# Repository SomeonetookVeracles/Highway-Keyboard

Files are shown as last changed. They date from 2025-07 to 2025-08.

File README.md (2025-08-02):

I'm building a minimalistic keyboard, something simple and stripped down. It's my first time working on a large PCB, and I kept getting distracted by feature creep and add-ons. So I'm going back to basics. I want this to be a barebones board that helps me sharpen my skills and really dial in the core of what makes a great keyboard.

I learned a lot while doing this, and explored concepts like impedence matching and zones, something that I've done before but never really had to prioritize.

If I do this again, I'm using a ESP-32 chip, making a CPU clock with decoupling capacitors was exhausting and annoyed me to no small extent lmao.
473670760-d07d10b8-821d-4425-aa78-196647b4c1dc





# Bill of Materials

| Reference | Qty | Value | Footprint | Description | DigiKey Link | Amazon Link | Unit Price | Total Price |
|---|-----|---|---|---|---|---|---|---|
| **Capacitors** | | | | | | | | |
| C1 | 1 | 1uF | 0603 | Ceramic Capacitor | [YAGEO CC0603ZRY5V7BB105](https://www.digikey.com/en/products/detail/yageo/CC0603ZRY5V7BB105/2103110) | [0603 Capacitor Kit](https://www.amazon.com/100pcs-Multilayer-Ceramic-Capacitor-0-5pF/dp/B0DDC637G1) | $0.03 | $0.03 |
| C2,C3,C4 | 3 | 0.1uF | 0603 | Ceramic Capacitor | [KEMET C0603C104J4RAC7867](https://www.digikey.com/en/products/detail/kemet/C0603C104J4RAC7867/411096) | [0603 Capacitor Kit](https://www.amazon.com/100pcs-Multilayer-Ceramic-Capacitor-0-5pF/dp/B0DDC637G1) | $0.02 | $0.06 |
| C5 | 1 | 10uF | 0603 | Ceramic Capacitor | [YAGEO CC0603KRX5R6BB106](https://www.digikey.com/en/products/detail/yageo/CC0603KRX5R6BB106/5195191) | [0603 Capacitor Kit](https://www.amazon.com/100pcs-Multilayer-Ceramic-Capacitor-0-5pF/dp/B0DDC637G1) | $0.08 | $0.08 |
| C6,C7 | 2 | 22pF | 0603 | Ceramic Capacitor | [DigiKey 0603 Capacitors](https://www.digikey.com/en/products/filter/ceramic-capacitors/60) | [0603 Capacitor Kit](https://www.amazon.com/100pcs-Multilayer-Ceramic-Capacitor-0-5pF/dp/B0DDC637G1) | $0.02 | $0.04 |
| **Diodes** | | | | | | | | |
| D1-D87 | 87 | D_Small | 0603 | Small Signal Diode | [DigiKey 0603 Diodes](https://www.digikey.com/en/products/filter/diodes-rectifiers-single/280) | [SMD Component Kit](https://www.amazon.com/Component-Assortment-Capacitor-Transistor-Soldering/dp/B07GMRJC1Q) | $0.05 | $4.35 |
| **Fuse** | | | | | | | | |
| F1 | 1 | 500mA | 1812 | PTC Resettable Fuse | [Bourns MF-MSMF050-2](https://www.digikey.com/en/products/detail/bourns-inc/MF-MSMF050-2/662832) | [Fuse Kit](https://www.amazon.com/s?k=500mA+PTC+fuse) | $0.32 | $0.32 |
| **Connectors** | | | | | | | | |
| J1 | 1 | USB_C_Receptacle | HRO TYPE-C-31-M-12 | USB-C 2.0 Connector | [JAE DX07S016JA3R1500](https://www.digikey.com/en/products/detail/jae-electronics/DX07S016JA3R1500/5978550) | [USB-C Connector](https://www.amazon.com/s?k=TYPE-C-31-M-12) | $0.38 | $0.38 |
| **Resistors** | | | | | | | | |
| R1,R4 | 2 | 10k | 0603 | Chip Resistor | [YAGEO RC0603JR-0710KL](https://www.digikey.com/en/products/detail/yageo/RC0603JR-0710KL/726700) | [0603 Resistor Kit](https://www.amazon.com/s?k=0603+resistor+kit) | $0.01 | $0.02 |
| R2,R3 | 2 | 22Ω | 0603 | Chip Resistor | [DigiKey 0603 Resistors](https://www.digikey.com/en/products/filter/resistors/chip-resistor-surface-mount/0603/52) | [0603 Resistor Kit](https://www.amazon.com/s?k=0603+resistor+kit) | $0.01 | $0.02 |
| R5 | 1 | 1M | 0603 | Chip Resistor | [DigiKey 0603 Resistors](https://www.digikey.com/en/products/filter/resistors/chip-resistor-surface-mount/0603/52) | [0603 Resistor Kit](https://www.amazon.com/s?k=0603+resistor+kit) | $0.01 | $0.01 |
| R6,R7 | 2 | 5.11k | 0603 | Chip Resistor | [DigiKey 0603 Resistors](https://www.digikey.com/en/products/filter/resistors/chip-resistor-surface-mount/0603/52) | [0603 Resistor Kit](https://www.amazon.com/s?k=0603+resistor+kit) | $0.01 | $0.02 |
| **Switches** | | | | | | | | |
| SW1-SW87 | 87 | SW_Push_45deg | Cherry MX Compatible | Mechanical Key Switch | [Cherry MX1A-E1NW](https://www.digikey.com/en/products/detail/cherry-americas-llc/MX1A-E1NW/20180) | [Cherry MX Switches](https://www.amazon.com/s?k=cherry+mx+switches) | $1.25 | $108.75 |
| SWRST1 | 1 | SW_PUSH | SMD Tactile | Reset Switch | [DigiKey Tactile Switches](https://www.digikey.com/en/products/filter/tactile-switches/197) | [Tactile Switch Kit](https://www.amazon.com/s?k=SMD+tactile+switch) | $0.15 | $0.15 |
| **Microcontroller** | | | | | | | | |
| U1 | 1 | ATmega32U4-A | TQFP-44 | 8-bit Microcontroller | [ATMEGA32U4-AU](https://www.digikey.com/en/products/detail/microchip-technology/ATMEGA32U4-AU/1914602) | [ATmega32U4 Module](https://www.amazon.com/s?k=atmega32u4) | $5.39 | $5.39 |
| **Crystal** | | | | | | | | |
| Y1 | 1 | 16MHz | 0603-4Pin | Crystal Oscillator | [TXC 7V-16.000MAAE-T](https://www.digikey.com/en/products/detail/txc-corporation/7V-16-000MAAE-T/2626978) | [16MHz Crystal](https://www.amazon.com/s?k=16MHz+crystal+SMD) | $0.35 | $0.35 |

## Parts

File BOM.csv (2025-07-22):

Reference | Qty | Value | DNP | Exclude from BOM | Exclude from Board | Footprint | Datasheet
C1 | 1 | 1uF |  |  |  | Capacitor_SMD:C_0201_0603Metric_Pad0.64x0.40mm_HandSolder | ~
C2,C3,C4 | 3 | 0.1uF |  |  |  | Capacitor_SMD:C_0201_0603Metric_Pad0.64x0.40mm_HandSolder | ~
C5 | 1 | 10uF |  |  |  | Capacitor_SMD:C_0201_0603Metric_Pad0.64x0.40mm_HandSolder | ~
C6,C7 | 2 | 22pF |  |  |  | Capacitor_SMD:C_0201_0603Metric_Pad0.64x0.40mm_HandSolder | ~
D1,D2,D3,D4,D5,D6,D7,D8,D9,D10,D11,D12,D13,D14,D15,D16,D17,D18,D19,D20,D21,D22,D23,D24,D25,D26,D27,D28,D29,D30,D31,D32,D33,D34,D35,D36,D37,D38,D39,D40,D41,D42,D43,D44,D45,D46,D47,D48,D49,D50,D51,D52,D53,D54,D55,D56,D57,D58,D59,D60,D61,D62,D63,D64,D65,D66,D67,D68,D69,D70,D71,D72,D73,D74,D75,D76,D77,D78,D79,D80,D81,D82,D83,D84,D85,D86,D87 | 87 | D_Small |  |  |  | Diode_SMD:D_0603_1608Metric_Pad1.05x0.95mm_HandSolder | ~
F1 | 1 | 500mA |  |  |  | Fuse:Fuse_Bourns_MF-RG500 | ~
J1 | 1 | USB_C_Receptacle_USB2.0_14P |  |  |  | Connector_USB:USB_C_Receptacle_HRO_TYPE-C-31-M-12 | https://www.usb.org/sites/default/files/documents/usb_type-c.zip
R1,R4 | 2 | 10k |  |  |  | Resistor_SMD:R_0201_0603Metric_Pad0.64x0.40mm_HandSolder | ~
R2,R3 | 2 | 22 |  |  |  | Resistor_SMD:R_0201_0603Metric_Pad0.64x0.40mm_HandSolder | ~
R5 | 1 | 1M |  |  |  | Resistor_SMD:R_0201_0603Metric_Pad0.64x0.40mm_HandSolder | ~
R6,R7 | 2 | 5.11k |  |  |  | Resistor_SMD:R_0201_0603Metric_Pad0.64x0.40mm_HandSolder | ~
SW1,SW2,SW3,SW4,SW5,SW6,SW7,SW8,SW9,SW10,SW11,SW12,SW13,SW14,SW15,SW16,SW17,SW18,SW19,SW20,SW21,SW22,SW23,SW24,SW25,SW26,SW27,SW28,SW29,SW30,SW31,SW32,SW33,SW34,SW35,SW36,SW37,SW38,SW39,SW40,SW41,SW42,SW43,SW44,SW45,SW46,SW47,SW48,SW49,SW50,SW51,SW52,SW53,SW54,SW55,SW56,SW57,SW58,SW59,SW60,SW61,SW62,SW63,SW64,SW65,SW66,SW67,SW68,SW69,SW70,SW71,SW72,SW73,SW74,SW75,SW76,SW77,SW78,SW79,SW80,SW81,SW82,SW83,SW84,SW85,SW86,SW87 | 87 | SW_Push_45deg |  |  |  | PCM_Switch_Keyboard_Hybrid:SW_Hybrid_Cherry_MX_Alps | ~
SWRST1 | 1 | SW_PUSH |  |  |  | Button_Switch_SMD:SW_Push_1P1T_NO_CK_KMR2
U1 | 1 | ATmega32U4-A |  |  |  | Package_QFP:TQFP-44_10x10mm_P0.8mm | http://ww1.microchip.com/downloads/en/DeviceDoc/Atmel-7766-8-bit-AVR-ATmega16U4-32U4_Datasheet.pdf
Y1 | 1 | 16MHz |  |  |  | Crystal:Crystal_SMD_0603-4Pin_6.0x3.5mm_HandSoldering | ~

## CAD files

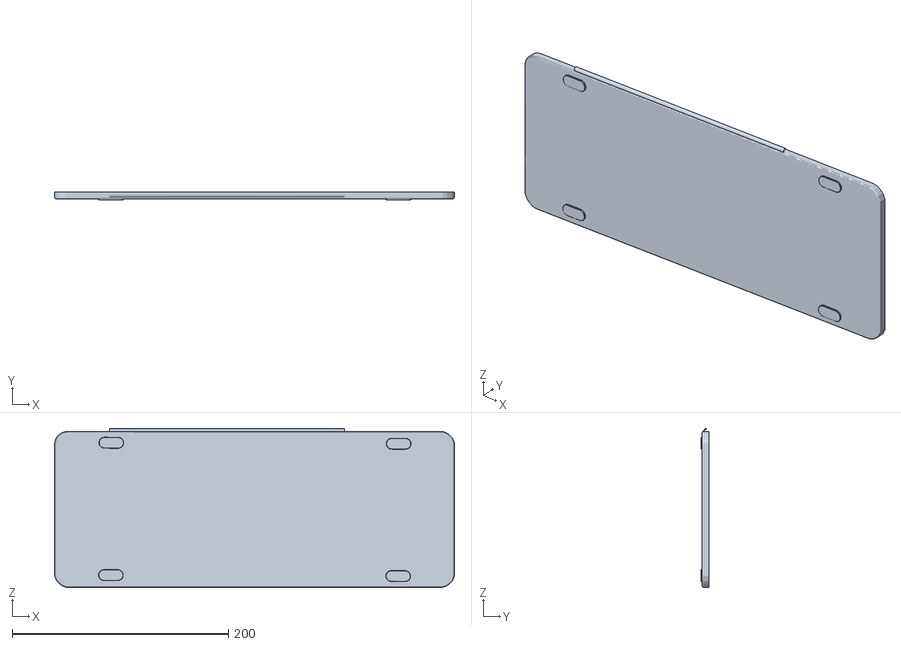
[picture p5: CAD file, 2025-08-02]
100% Keyboard/CAD Files/Bottom.STL
369.6 x 7.65 x 146.9

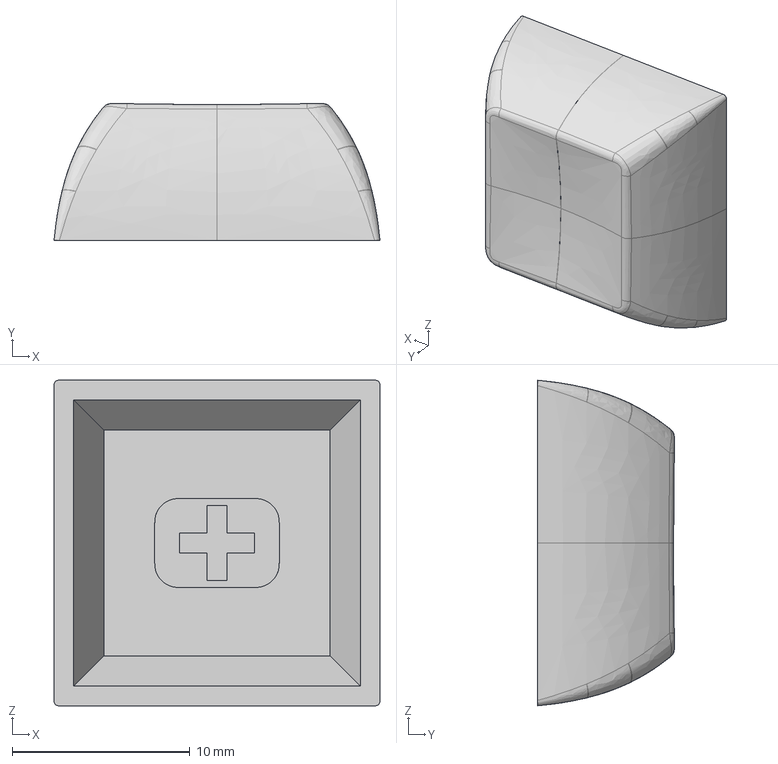
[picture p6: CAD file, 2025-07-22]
100% Keyboard/CAD Files/dsa-keycap-for-cherry-mx-switches-1.snapshot.4/DSA_Keycap_CherryMX.step
18.3 x 7.69 x 18.3 mm

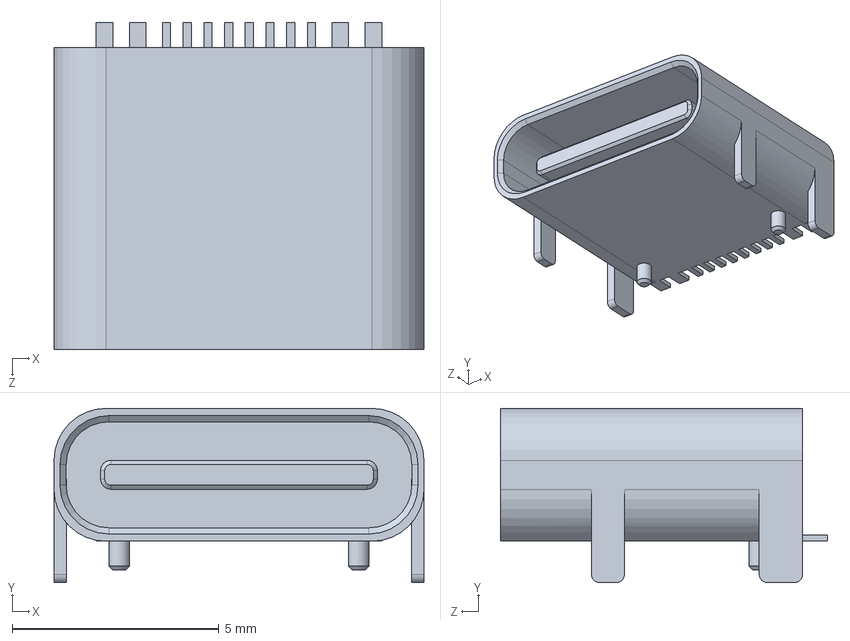
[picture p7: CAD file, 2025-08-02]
100% Keyboard/CAD Files/HRO TYPE-C-31-M-12.SLDPRT
8.94 x 4.21 x 7.90 mm

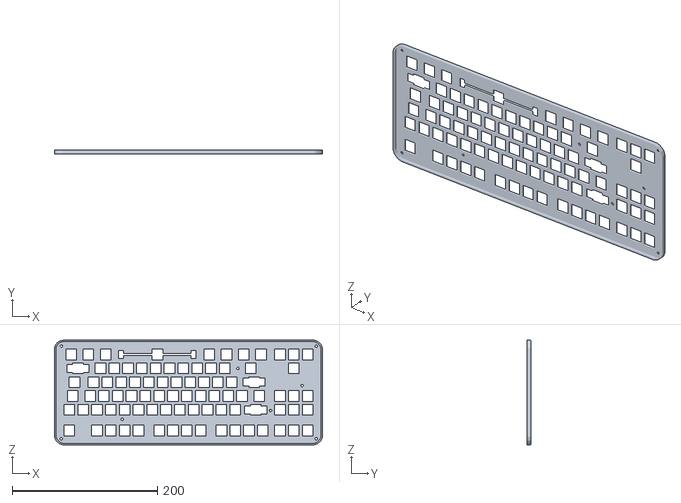
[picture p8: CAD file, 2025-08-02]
100% Keyboard/CAD Files/Top.STL
369.6 x 5.14 x 144.3

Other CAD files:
100% Keyboard/CAD Files/Top 2.STL
100% Keyboard/CAD Files/Bottom 2.STL
100% Keyboard/CAD Files/dsa-keycap-for-cherry-mx-switches-1.snapshot.4/Keycap_adjusted v39.f3d

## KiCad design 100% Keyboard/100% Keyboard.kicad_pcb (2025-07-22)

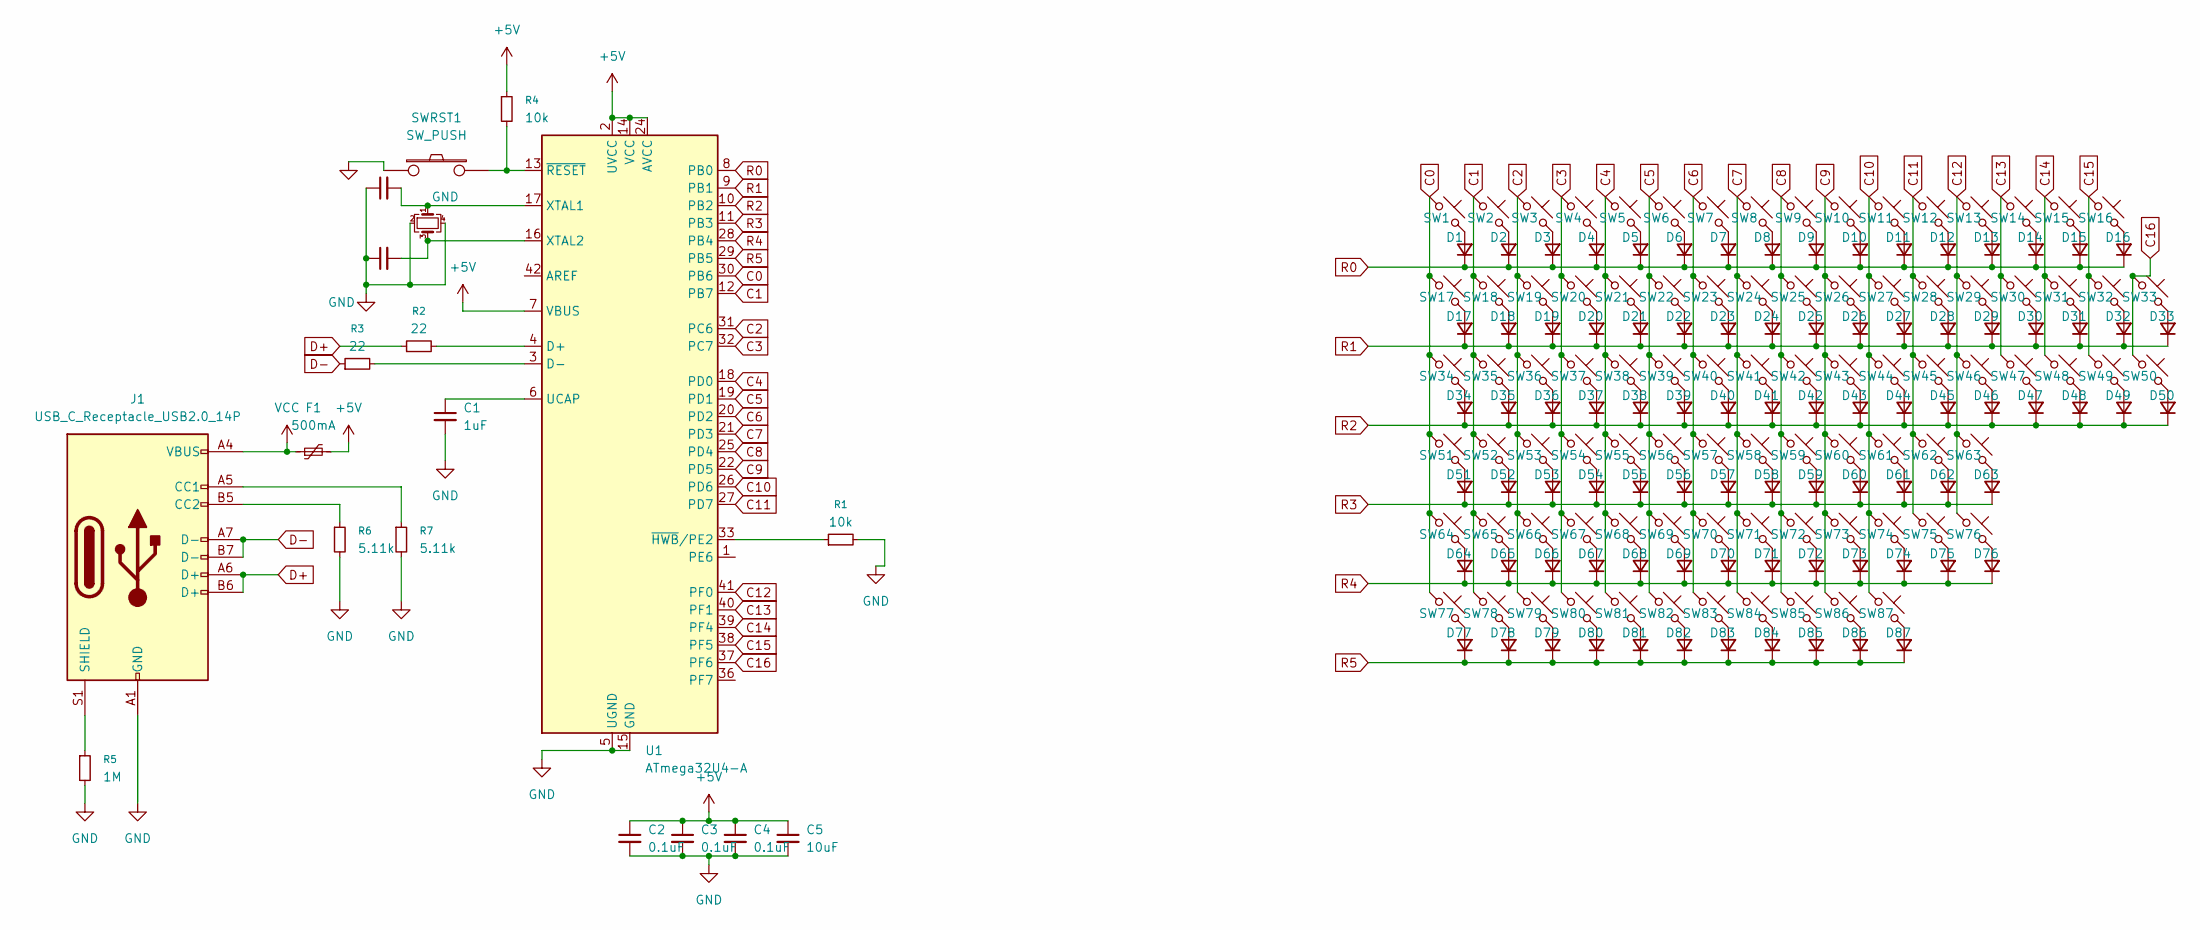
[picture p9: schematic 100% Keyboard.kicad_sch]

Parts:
C1: 1uF; C_0201_0603Metric_Pad0.64x0.40mm_HandSolder
C2, C3, C4: 0.1uF; C_0201_0603Metric_Pad0.64x0.40mm_HandSolder
C5: 10uF; C_0201_0603Metric_Pad0.64x0.40mm_HandSolder
C6, C7: 22pF; C_0201_0603Metric_Pad0.64x0.40mm_HandSolder
D1, D2, D3, D4, D5, D6, D7, D8, D9, D10, D11, D12, D13, D14, D15, D16, D17, D18, D19, D20, D21, D22, D23, D24, D25, D26, D27, D28, D29, D30, D31, D32, D33, D34, D35, D36, D37, D38, D39, D40, D41, D42, D43, D44, D45, D46, D47, D48, D49, D50, D51, D52, D53, D54, D55, D56, D57, D58, D59, D60, D61, D62, D63, D64, D65, D66, D67, D68, D69, D70, D71, D72, D73, D74, D75, D76, D77, D78, D79, D80, D81, D82, D83, D84, D85, D86, D87: D_Small; D_0603_1608Metric_Pad1.05x0.95mm_HandSolder
F1: 500mA; Fuse_Bourns_MF-RG500
J1: USB_C_Receptacle_USB2.0_14P; USB_C_Receptacle_HRO_TYPE-C-31-M-12
R1, R4: 10k; R_0201_0603Metric_Pad0.64x0.40mm_HandSolder
R2, R3: 22; R_0201_0603Metric_Pad0.64x0.40mm_HandSolder
R5: 1M; R_0201_0603Metric_Pad0.64x0.40mm_HandSolder
R6, R7: 5.11k; R_0201_0603Metric_Pad0.64x0.40mm_HandSolder
SW1, SW2, SW3, SW4, SW5, SW6, SW7, SW8, SW9, SW10, SW11, SW12, SW13, SW14, SW15, SW16, SW17, SW18, SW19, SW20, SW21, SW22, SW23, SW24, SW25, SW26, SW27, SW28, SW29, SW30, SW31, SW32, SW33, SW34, SW35, SW36, SW37, SW38, SW39, SW40, SW41, SW42, SW43, SW44, SW45, SW46, SW47, SW48, SW49, SW50, SW51, SW52, SW53, SW54, SW55, SW56, SW57, SW58, SW59, SW60, SW61, SW62, SW63, SW64, SW65, SW66, SW67, SW68, SW69, SW70, SW71, SW72, SW73, SW74, SW75, SW76, SW77, SW78, SW79, SW80, SW81, SW82, SW83, SW84, SW85, SW86, SW87: SW_Push_45deg; SW_Hybrid_Cherry_MX_Alps
SWRST1: SW_PUSH; SW_Push_1P1T_NO_CK_KMR2
U1: ATmega32U4-A; TQFP-44_10x10mm_P0.8mm
Y1: 16MHz; Crystal_SMD_0603-4Pin_6.0x3.5mm_HandSoldering

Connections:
+5V: C2.1, C3.1, C4.1, C5.1, F1.2, R4.1, U1.2 (UVCC), U1.7 (VBUS), U1.14 (VCC), U1.24 (AVCC), U1.34 (VCC), U1.44 (AVCC)
C0: SW1.1, SW17.1, SW34.1, SW51.1, SW64.1, SW77.1, U1.30 (PB6)
C1: SW2.1, SW18.1, SW35.1, SW52.1, SW65.1, SW78.1, U1.12 (PB7)
C2: SW3.1, SW19.1, SW36.1, SW53.1, SW66.1, SW79.1, U1.31 (PC6)
C3: SW4.1, SW20.1, SW37.1, SW54.1, SW67.1, SW80.1, U1.32 (PC7)
C4: SW5.1, SW21.1, SW38.1, SW55.1, SW68.1, SW81.1, U1.18 (PD0)
C5: SW6.1, SW22.1, SW39.1, SW56.1, SW69.1, SW82.1, U1.19 (PD1)
C6: SW7.1, SW23.1, SW40.1, SW57.1, SW70.1, SW83.1, U1.20 (PD2)
C7: SW8.1, SW24.1, SW41.1, SW58.1, SW71.1, SW84.1, U1.21 (PD3)
C8: SW9.1, SW25.1, SW42.1, SW59.1, SW72.1, SW85.1, U1.25 (PD4)
C9: SW10.1, SW26.1, SW43.1, SW60.1, SW73.1, SW86.1, U1.22 (PD5)
C10: SW11.1, SW27.1, SW44.1, SW61.1, SW74.1, SW87.1, U1.26 (PD6)
C11: SW12.1, SW28.1, SW45.1, SW62.1, SW75.1, U1.27 (PD7)
C12: SW13.1, SW29.1, SW46.1, SW63.1, SW76.1, U1.41 (PF0)
C13: SW14.1, SW30.1, SW47.1, U1.40 (PF1)
C14: SW15.1, SW31.1, SW48.1, U1.39 (PF4)
C15: SW16.1, SW32.1, SW49.1, U1.38 (PF5)
C16: SW33.1, SW50.1, U1.37 (PF6)
D+: J1.A6 (D+), J1.B6 (D+), R2.1
D-: J1.A7 (D-), J1.B7 (D-), R3.1
GND: C1.2, C2.2, C3.2, C4.2, C5.2, C6.1, C7.1, J1.A1 (GND), J1.A12 (GND), J1.B1 (GND), J1.B12 (GND), R1.2, R5.2, R6.2, R7.2, SWRST1.1, U1.5 (UGND), U1.15 (GND), U1.23 (GND), U1.35 (GND), U1.43 (GND), Y1.2, Y1.4
unnamed: D1.2 (A), SW1.2
unnamed: D2.2 (A), SW2.2
unnamed: D3.2 (A), SW3.2
unnamed: D4.2 (A), SW4.2
unnamed: D5.2 (A), SW5.2
unnamed: D6.2 (A), SW6.2
unnamed: D7.2 (A), SW7.2
unnamed: D8.2 (A), SW8.2
unnamed: D9.2 (A), SW9.2
unnamed: D10.2 (A), SW10.2
unnamed: D11.2 (A), SW11.2
unnamed: D12.2 (A), SW12.2
unnamed: D13.2 (A), SW13.2
unnamed: D14.2 (A), SW14.2
unnamed: D15.2 (A), SW15.2
unnamed: D16.2 (A), SW16.2
unnamed: D17.2 (A), SW17.2
unnamed: D18.2 (A), SW18.2
unnamed: D19.2 (A), SW19.2
unnamed: D20.2 (A), SW20.2
unnamed: D21.2 (A), SW21.2
unnamed: D22.2 (A), SW22.2
unnamed: D23.2 (A), SW23.2
unnamed: D24.2 (A), SW24.2
unnamed: D25.2 (A), SW25.2
unnamed: D26.2 (A), SW26.2
unnamed: D27.2 (A), SW27.2
unnamed: D28.2 (A), SW28.2
unnamed: D29.2 (A), SW29.2
unnamed: D30.2 (A), SW30.2
unnamed: D31.2 (A), SW31.2
unnamed: D32.2 (A), SW32.2
unnamed: D33.2 (A), SW33.2
unnamed: D34.2 (A), SW34.2
unnamed: D35.2 (A), SW35.2
unnamed: D36.2 (A), SW36.2
unnamed: D37.2 (A), SW37.2
unnamed: D38.2 (A), SW38.2
unnamed: D39.2 (A), SW39.2
unnamed: D40.2 (A), SW40.2
unnamed: D41.2 (A), SW41.2
unnamed: D42.2 (A), SW42.2
unnamed: D43.2 (A), SW43.2
unnamed: D44.2 (A), SW44.2
unnamed: D45.2 (A), SW45.2
unnamed: D46.2 (A), SW46.2
unnamed: D47.2 (A), SW47.2
unnamed: D48.2 (A), SW48.2
unnamed: D49.2 (A), SW49.2
unnamed: D50.2 (A), SW50.2
unnamed: D51.2 (A), SW51.2
unnamed: D52.2 (A), SW52.2
unnamed: D53.2 (A), SW53.2
unnamed: D54.2 (A), SW54.2
unnamed: D55.2 (A), SW55.2
unnamed: D56.2 (A), SW56.2
unnamed: D57.2 (A), SW57.2
unnamed: D58.2 (A), SW58.2
unnamed: D59.2 (A), SW59.2
unnamed: D60.2 (A), SW60.2
unnamed: D61.2 (A), SW61.2
unnamed: D62.2 (A), SW62.2
unnamed: D63.2 (A), SW63.2
unnamed: D64.2 (A), SW64.2
unnamed: D65.2 (A), SW65.2
unnamed: D66.2 (A), SW66.2
unnamed: D67.2 (A), SW67.2
unnamed: D68.2 (A), SW68.2
unnamed: D69.2 (A), SW69.2
unnamed: D70.2 (A), SW70.2
unnamed: D71.2 (A), SW71.2
unnamed: D72.2 (A), SW72.2
unnamed: D73.2 (A), SW73.2
unnamed: D74.2 (A), SW74.2
unnamed: D75.2 (A), SW75.2
unnamed: D76.2 (A), SW76.2
unnamed: D77.2 (A), SW77.2
unnamed: D78.2 (A), SW78.2
unnamed: D79.2 (A), SW79.2
unnamed: D80.2 (A), SW80.2
unnamed: D81.2 (A), SW81.2
unnamed: D82.2 (A), SW82.2
unnamed: D83.2 (A), SW83.2
unnamed: D84.2 (A), SW84.2
unnamed: D85.2 (A), SW85.2
unnamed: D86.2 (A), SW86.2
unnamed: D87.2 (A), SW87.2
unnamed: J1.A5 (CC1), R7.1
unnamed: J1.B5 (CC2), R6.1
unnamed: J1.S1 (SHIELD), R5.1
unnamed: R2.2, U1.4 (D+)
unnamed: R3.2, U1.3 (D-)
unnamed: C1.1, U1.6 (UCAP)
unnamed: C6.2, U1.17 (XTAL1), Y1.1
unnamed: C7.2, U1.16 (XTAL2), Y1.3
unnamed: R1.1, U1.33 (~HWB/PE2)
unnamed: R4.2, SWRST1.2, U1.13 (~RESET)
R0: D1.1 (K), D2.1 (K), D3.1 (K), D4.1 (K), D5.1 (K), D6.1 (K), D7.1 (K), D8.1 (K), D9.1 (K), D10.1 (K), D11.1 (K), D12.1 (K), D13.1 (K), D14.1 (K), D15.1 (K), D16.1 (K), U1.8 (PB0)
R1: D17.1 (K), D18.1 (K), D19.1 (K), D20.1 (K), D21.1 (K), D22.1 (K), D23.1 (K), D24.1 (K), D25.1 (K), D26.1 (K), D27.1 (K), D28.1 (K), D29.1 (K), D30.1 (K), D31.1 (K), D32.1 (K), D33.1 (K), U1.9 (PB1)
R2: D34.1 (K), D35.1 (K), D36.1 (K), D37.1 (K), D38.1 (K), D39.1 (K), D40.1 (K), D41.1 (K), D42.1 (K), D43.1 (K), D44.1 (K), D45.1 (K), D46.1 (K), D47.1 (K), D48.1 (K), D49.1 (K), D50.1 (K), U1.10 (PB2)
R3: D51.1 (K), D52.1 (K), D53.1 (K), D54.1 (K), D55.1 (K), D56.1 (K), D57.1 (K), D58.1 (K), D59.1 (K), D60.1 (K), D61.1 (K), D62.1 (K), D63.1 (K), U1.11 (PB3)
R4: D64.1 (K), D65.1 (K), D66.1 (K), D67.1 (K), D68.1 (K), D69.1 (K), D70.1 (K), D71.1 (K), D72.1 (K), D73.1 (K), D74.1 (K), D75.1 (K), D76.1 (K), U1.28 (PB4)
R5: D77.1 (K), D78.1 (K), D79.1 (K), D80.1 (K), D81.1 (K), D82.1 (K), D83.1 (K), D84.1 (K), D85.1 (K), D86.1 (K), D87.1 (K), U1.29 (PB5)
VCC: F1.1, J1.A4 (VBUS), J1.A9 (VBUS), J1.B4 (VBUS), J1.B9 (VBUS)

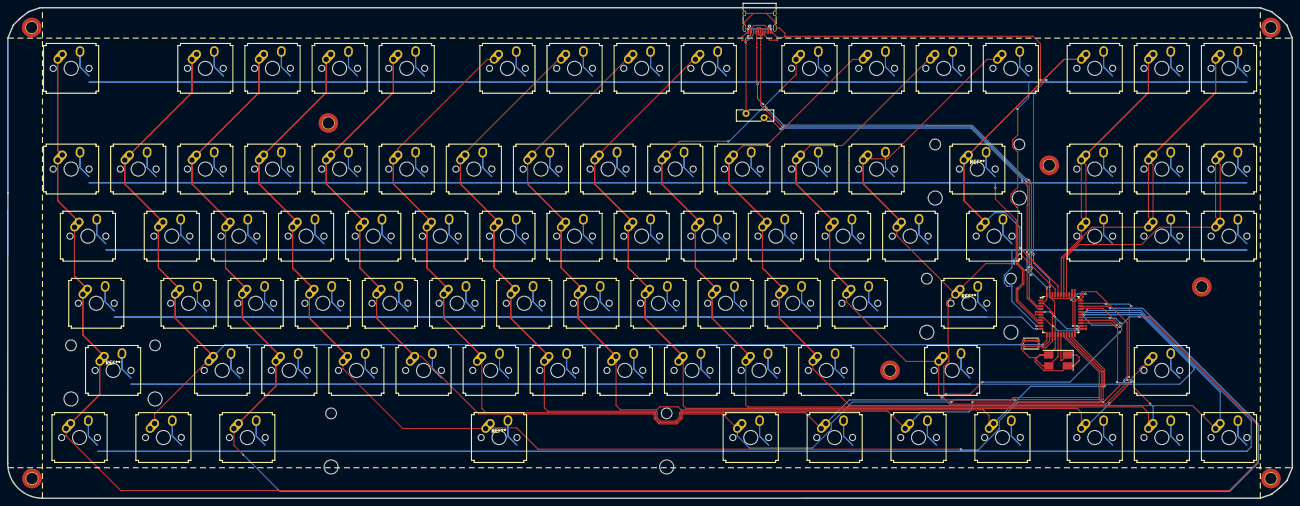
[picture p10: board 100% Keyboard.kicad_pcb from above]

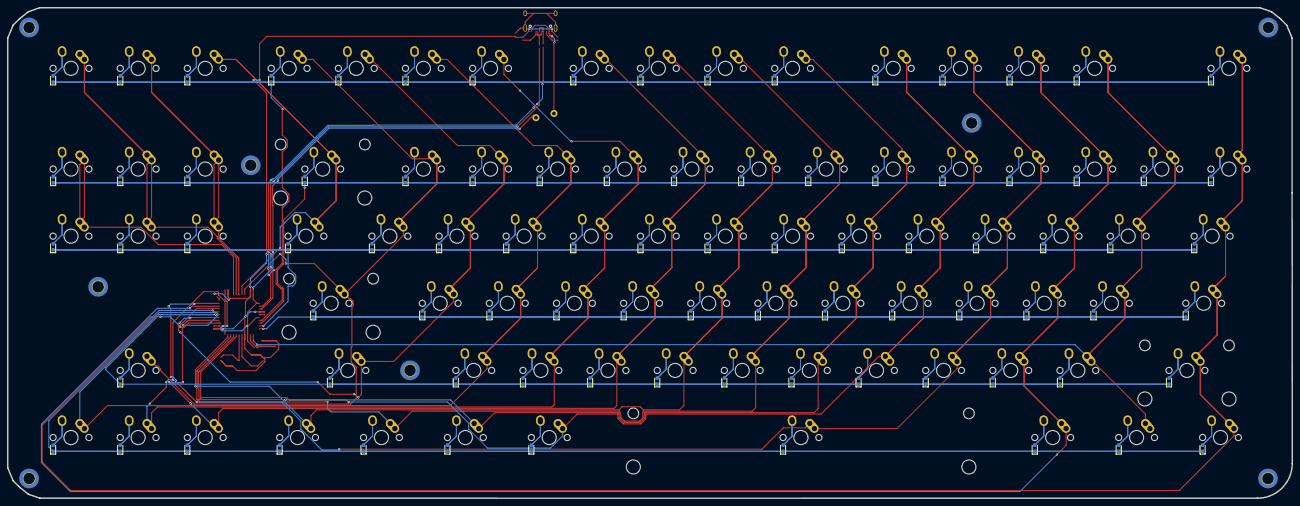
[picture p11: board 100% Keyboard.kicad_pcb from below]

Board: 2 copper layers, 364.6 x 139.2 mm, 193 parts (87 on the bottom side), 125 nets.

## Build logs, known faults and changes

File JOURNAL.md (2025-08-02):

---
title: "HC Standard Keyboard"
author: "Owen Borgos, or Veracles"
description: "This will be a standard 100% keyboard design, with a screen and rotary encoder, as well as an SD card reader.
created_at: "2025-06-5"
---

# June 8th, began designing PCB

**(Quick note, I lost all my progress about halfway through, and rebuilt it, so all of these first entries are sparser, pls read to the end for the real journal!)**

Created chip, clock, and wiring, will do sd card reader and USB-c tomorrow.


**Total time spent: 2.5 Hours**

# June 9th, WHY WONT SWITCHES APPEAR
Added USB-C, But for some reason the SWITCHES WONT APPEAR. (I found out after this that the switches that show up in the kicad plugin manager are PCB only, your just supposed to use a generic switch symbol...)


**Total time spent: 3.5 Hours**

# June 22nd, Finally fixed the great switch dilemma
I got switches working finally, and got them mapped to the blueprint:


**Total time spent: 5 Hours**

# June 23rd, Added some cool stuff
Playing around with using through holes and hand soldering to give me more flexibility with an OLED Screen and Rotary encoder, will update if there's progress.
I also added a MCP 23017 to give me additional GPIO for fun stuff like the screen and encoder.


**Total time spent: 7 Hours**

# July 21st, Redid a ton of stuff
I reinstalled windows on my computer and lost literally all of my data, including my backups, and the github version was corrupted for some reason, so I decided to rebuild the board from scratch, using a few new tricks I learned from my business card PCB I did as a distraction.

It's a bit (super duper) cursed, but I got most of the wiring done:

FINALLY GOT IT TOGETHER, I'M GONNA LOSE MY MIND

I also added a few more holes for screws, for added stability, these'll be added using heat threaded inserts, as I have a few spare I accidentally stole from my school.


I then did the case, this took a while (3 hours) because I had to manually cut out the holes for each switch, and fiddle with the tolerances on it so it would fit better later on.


I FINISHED THE CASE! (The holes for the switches are there I had to suppress them because of lag :sob:)


**Total time spent: 19 hours**

# August 2nd, the resubmission
I got told I needed to add more detail to the case, so I decided to redesign it to include a chamfered edge around the individual keyholes, and optimizing the geometry of the case to be more 3d printer friendly. I also made the top out of a clear plastic, and I plan on using a SLA printer with clear resin to make it transparent, showing off the PCB and the art I'm adding to the silkscreen. The bottom will be made of orange ABS filament, sanded down. I also fixed the stabilizers so they actually will work physically.

The main board showcase


The rubber feet I put on the bottom:


I also added a cable holder at the back to nestle it into (hard to see here but it'll be printed in SLA and mounted seperately)


Thanks for reading!

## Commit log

2025-06-23 First push (i forgor)
    [Highway-Keyboard.kicad_pcb, Highway-Keyboard.kicad_sch]
2025-07-22 Kill me
    [100% Keyboard.csv, 100% Keyboard.kicad_pcb, 100% Keyboard.kicad_pcb_bom.csv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]
2025-07-27 Added BOM
    [BOM.csv]
